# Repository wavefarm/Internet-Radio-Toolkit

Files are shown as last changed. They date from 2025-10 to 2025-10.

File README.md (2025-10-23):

Wave Farm's Transmission and Sound Art Toolkit

For organizations and Wave Farm Transmit Partners, the Transmission and Sound Art Toolkit is a self-contained kit that enables live audio streaming via WiFi using either the Toolkit’s built-in microphone or line-in audio. The Toolkit communicates with Wave Farm’s Icecast server to provide online audio streaming and automatically records and publishes audio archives. For artists, the Toolkit is an Arduino-based open source expandable platform for telematic performance and remote sonic and physical interaction.

This repo contains the hardware design files in EAGLE CAD format, manufacturing files, Arduino code and enclosure files in OpenSCAD and STL formats.

The project is based on the ESP32W-ROVER platform and the VLSI VS1063 IC.

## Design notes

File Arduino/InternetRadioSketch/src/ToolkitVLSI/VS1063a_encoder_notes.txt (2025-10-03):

Chapter 11.6 of the Data Sheet
------------------------------

Encoding Control Registers

SCI_MODE    bits 2,12,14 SM_RESET, SM_ENCODE, SM_LINE1
    Line 1 instead of mic is used if SM_LINE1 is set

SCI_AICTRL0 bits 15:0 Sample Rate 8000 - 48000 (read at encoding startup)

SCI_AICTRL1 bits 15:0 Gain 1024=1x 0=AGC
    gain is SCI_AICTRL1/1024

SCI_AICTRL2 Max autogain 1024=1x, 65535=64x

SCI_AICTRL3 15 codec mode (enable SDI data encoded to HDAT0 HDAT1)
            14 AEC enable (Acoustic Echo Cancellation)
            13 UART (8N1) TX enable (Send encoded data out the serial port)
                setup parametric_x.i.encoding for serial port params
            12 reserved, set to 0
            11 Pause enable
            10 No RIFF WAV header inserted (or expected)
            8:9 reserved set to 0
            7:4 encoding format 0 .. 6
                0=IMA ADPCM, 1=PCM, 5=Ogg, 6=MP3
            3 reserved set to 0
            2:0 ADC mode 0 .. 4
                0=joint stereo (common AGC), 1=dual stereo (separate AGC),
                2=left channel, 3=right channel, 4=mono mix

SCI_WRAMADDR bits 15:0 Quality/bit rate selection for Ogg and MP3
    Use 0xe080 for CBR 128kbps
            15:14 bitrate mode 0=quality mode, 1=VBR, 2=ABR, 3=CBR
            13:12 bit rate multiplier 0=10,1=100,2=1000,3=10000
            11 ogg specific
            10 mp3: 1=do not use bit-reservoir (bit reservoir is 1 frame back)
            9 set to 0
            8:0 bit rate base 0 to 511 (or quality 0 to 9 in quality mode)

IF you use VS1063a Patches:
    activate encoding mode by first setting the bit SM_ENCODE in SCI_MODE
    then write 0x50 to SCI_AIADDR

IF NOT using patches:
    set bits SM_RESET and SM_ENCODE in SCI_MODE

BEFORE ACTIVATING the encoder:
    the use MUST write values to SCI_AICTRL0, SCI_AICTRL3, and SC_WRAMADDR
    these values are only read at encoding startup
    SCI_AICTRL1 and SCI_AICTRL2 can be altered at anytime.

-----------------------------------------------------------------------------
11.6.2 THE ENCODING PROCEDURE

1. Load the patches package

2. Set
    SCI_CLOCKF to 4.5x (for all encoders except Ogg) 4.5x is default
    see 11.6.9,11.13

    SCI_AICTRL0 thru 3
    SCI_WRAMADDR

    Activate encoding for the patches or not

3. Recording
    read data through SCI_HDAT0/SCI_HDAT1
    see 11.6.3
    SCI_HDAT1 contains number of 2 byte words available (or 0 if none)
    SCI_HDAT0 contains big-endian 2 byte words of data, read until HDAT1 is 0

4 Finalizing
    set SM_CANCEL in SCI_MODE
    wait 100 ms
    read all remaining words from SCI_HDAT0/SCI_HDAT1
    wait 100ms
    soft reset

Example on Page 62 ****

    LoadUserCode(vs1063apatch);
    WriteVS10xxRegister(SCI_AICTRL0, 44100U);   // 44100Hz
    WriteVS10xxRegister(SCI_AICTRL1, 1024U);    // manual gain 1.0x
    WriteVS10xxRegister(SCI_AICTRL2, 4096U);    // AGC max gain 4.0x (not used)
    WriteVS10xxRegister(SCI_AICTRL3, 0x60);     // mp3, joint stereo

    WriteVS10xxRegister(SCI_WRAMADDR, 0xE080);  // 128kbps

    NOTE: we are loading WRAMADDR with a value but we are NOT doing subsequent
    WRAM access on this address value. The value is read at encoder startup,
    so no WRAM access occurs at all. Thus the value can be anything and it
    won't trash any WRAM data.

    uint16_t mode = ReadVS10xxRegister(SCI_MODE);
    mode = mode | SM_ENCODE | SM_LINE1;
    WriteVS10xxRegister(SCI_MODE, mode);
    WriteVS10xxRegister(SCI_AIADDR, 0x50);      // start recording

    Standard sample rates are: 32000, 44100, 48000

-----------------------------------------------------------------------------
Monitoring. SCI_VOL can be changed during encoding to change monitoring volume

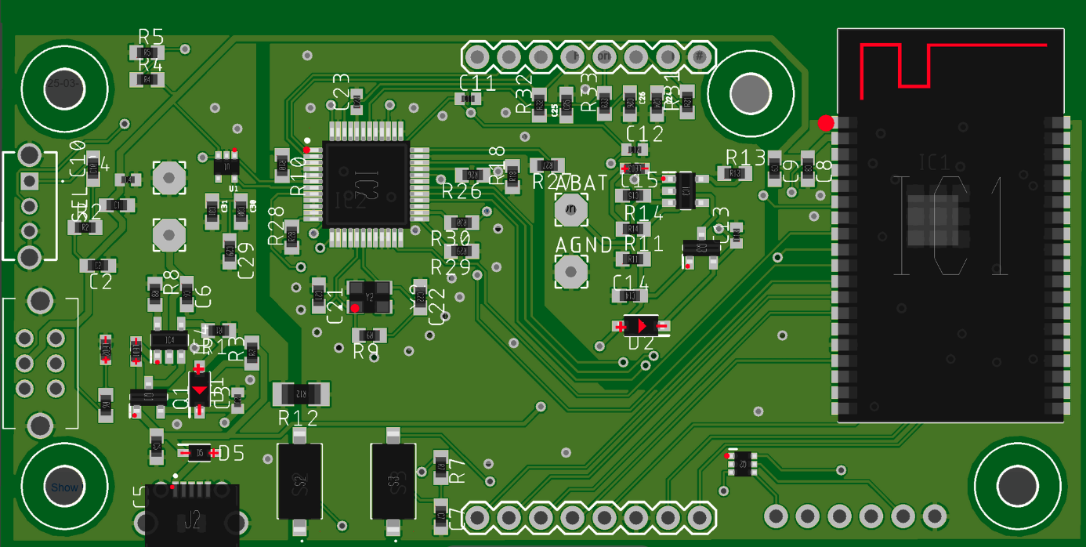
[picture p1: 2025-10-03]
Hardware/Gerbers/mainboard DFM.png

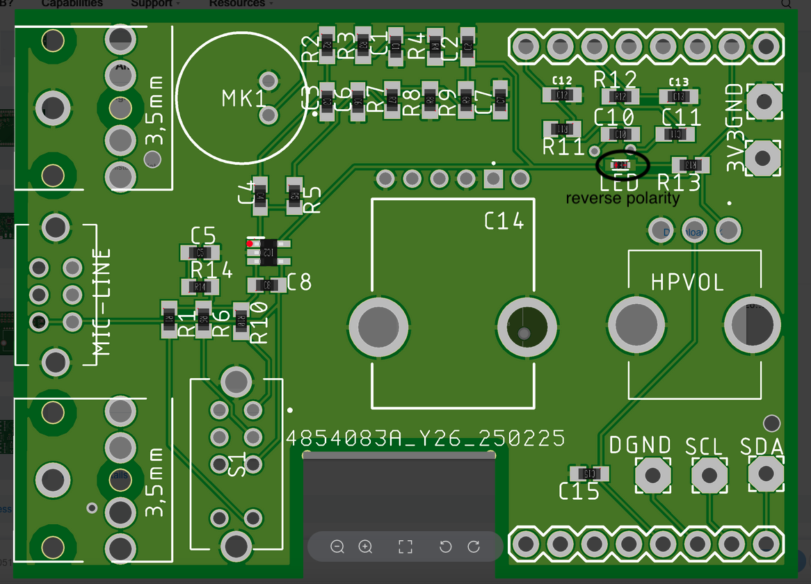
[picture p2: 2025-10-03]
Hardware/Gerbers/audioboard DFM.png

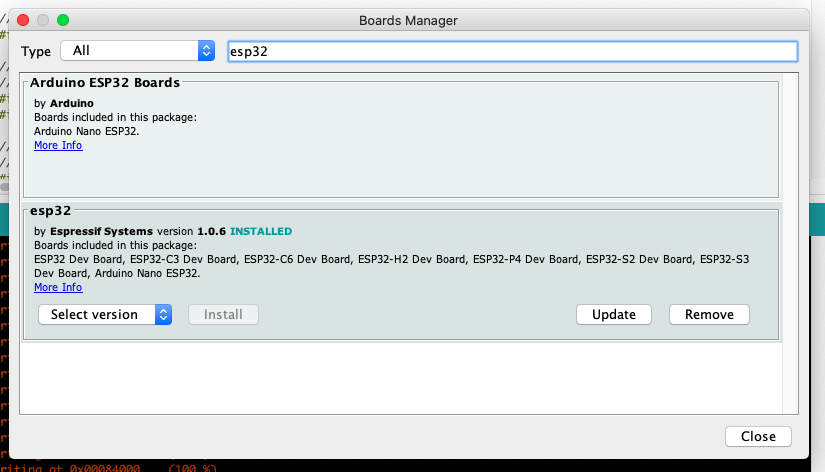
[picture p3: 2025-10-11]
Arduino/ide 1.8.19 settings/BoardManager_esp32_1.0.6.png

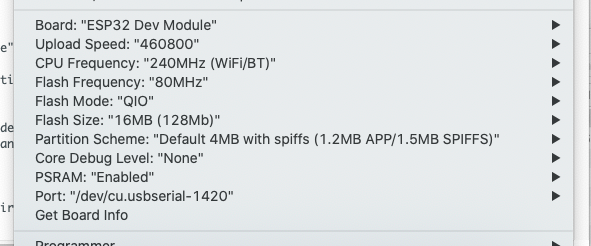
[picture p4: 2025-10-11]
Arduino/ide 1.8.19 settings/ToolMenu_BoardSettings.png

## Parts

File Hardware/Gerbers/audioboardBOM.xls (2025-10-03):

Comment | Designator | Footprint | JLCPCB Part #
10nF | C12,C13 | C0603 | C57112
R_18K_0603 | R5 | R0603 | C25810
R_15K_0603 | R7 | R0603 | C22809
C_47PF/50V_0603 | C3 | C0603 | C1671
LED | LED | SMARTLED-TTW | C273603
R_100R_0603 | R2 | R0603 | C22775
R_62K_0603 | R6 | R0603 | C23221
C_100NF/50V_0603 | C4 | C0603 | C14663
R_120K_0603 | R10 | R0603 | C25808
4K | R14 | R0603 | C2984443
C_100PF/50V_0603 | C8 | C0603 | C14858
MAX4466EXK+T | IC2 | SOT65P210X110-5N | C7456762
C_1UF/50V_0603 | C11,C10 | C0603 | C15849
C_2.2UF/16V_0603 | C6,C15 | C0603 | C23630
R_22K_0603 | R1 | R0603 | C31850
C_4.7UF/16V_0603 | C7 | C0603 | C19666
R_1K_0603 | R4 | R0603 | C21190
R_100K_0603 | R9,R8 | R0603 | C25803
R_470R_0603 | R12,R11 | R0603 | C23179
C_10UF/10V_0603 | C2,C1,C5 | C0603 | C19702
R_2.2K_0603 | R13,R3 | R0603 | C4190

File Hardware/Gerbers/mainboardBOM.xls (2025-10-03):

Comment | Designator | Footprint | JLCPCB Part #
R_0R_1206 | R12 | R1206 | C17888
10nF | C25,C24 | 0603-CAP | C57112
47nF | C26 | 0603-CAP | C1622
BAT760-7 | D5 | SOD2513X120N | C124187
MICROXNJ | J2 | MICROXNJ | C404969
VS1063A-L | IC2 | QFP50P900X900X160-48N | C486306
SXT32422AA48 | Y2 | SXT32422AA48 | C2901653
100nF | C31,C10,C7,C2,C30,C9 | C0603 | C14663
20 | R32,R31 | R0603 | C22950
Charge | LED2,LED1,LED3 | CHIP-LED0603 | C2286
10uF | C15,C14,C8,C29,C1,C6,C5 | C0603 | C19702
2k | R13,R14,R6,R3,R8 | R0603 | C22975
CJ2301_S1 | Q1,Q3 | SOT95P240X115-3N | C8547
UMH3NTN | Q2 | UMH3NTN | C123008
1uF | C23,C4,C12,C13,C11,C3 | C0402 | C52923
10 | R33 | R0603 | C22859
B5819W | D2,D1 | SOD3716X125N | C393519
TP4054-42-SOT25-R | IC3,IC4 | SOT95P280X100-5N | C32574
1.8V | U1 | SC70 | C266774
1M | R9 | R0603 | C22935
TS-1101-C-W | S2,S3 | TS1101CW | C318938
10k | R2,R7 | R0603 | C25804
100k | R4,R18,R27,R29,R30,R11,R1,R10,R28,R5,R26 | R0603 | C25803
22pF | C21,C22 | C0603 | C1634
ESP32-WROVER-E | IC1 | ESP32WROVERE | C529589

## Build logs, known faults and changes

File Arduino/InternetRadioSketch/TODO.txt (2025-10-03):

------------------------------------------------------------------------------
(1)
Add Kiosk mode

(a) kiosk_mode = 0 | 1 .. set via the hardware switch
if the hardware switch is ON (1) and there is a 'kiosk.html' file,
then serve kiosk.html .. otherwise operate with the normal
index.html file. The kiosk will stream whichever listen/transmit
stream is running through the system.

(b) if the transmit icy url == "" then we don't connect to an icy server
but we still stream through mp3 to the wifi server

(c) when the wifi server starts up it notes the startup ..
    _server_start_time = millis();
    _server_two_minute_timeout = false;
    _server_use_kiosk_page = false;

(d) when wifi server runs ..
    if (!_server_two_minute_timeout) {
        now = millis();
        if ((now - _server_start_time) > (120*1000)) {
            _server_two_minute_timeout = true;
            if (SettingItem::findUInt("kiosk_mode_is_on", 0)) {
                _server_use_kiosk_page = true;
            }
        }
    }

(e) kiosk.html
Use the play button + audio tag like in the config page, but make the
audio tag become visible only after the play button has been pressed.

------------------------------------------------------------------------------
(DONE)
Physical controls:
Peter your "listening mode selection" switch aka browser or icecast will be
coming in hot on pin 15 and the volume control pot will be on pin 35

------------------------------------------------------------------------------
(DONE)
Newer way to do load-on-play with the audio element

<audio controls="controls" preload="none">
</audio>

------------------------------------------------------------------------------
(DONE)
JS stuff for handling mobile

document.addEventListener("visibilitychange", () => {
  if (document.visibilityState === "hidden") {
    // We are now in the background
    // close the WS connection
  } else {
    // We have just come into the foreground
    // reconnect to the WS
  }
});

CHANGE the focus handler so that it checks for a connection and only
reconnects if we are disconnected.

------------------------------------------------------------------------------
(DONE)
Make the post file code compatible with binary uploads
i.e. we can't use the \0 terminator as a way to find the end
of the input buffer.

------------------------------------------------------------------------------
(DONE)
Change large static http buffer to a inbetween stream buffer

-> we want to use a short static buffer for GET requests and WS messages
-> BUT we need to be able to stream in POST requests
 The POST requests will have to block the server thread until the POST
 is finished.

------------------------------------------------------------------------------
(DONE)
UPLOAD page works.
We also need to support changing the Router SSID and Password via the default
page.
And the page should also post the local IP4 address if it knows it.
And also the AP IP4 address so you can use it on your phone

------------------------------------------------------------------------------
(DONE) .. maybe we can fix the bug when reconnecting to the AP on a phone

If the AP login page is still sitting in the browser then it assumes
that everything is already loaded and doesn't do a new load event.

window.addEventListener("focus", function(event)
{
    // check to make sure the WS is running and has updated settings
}, false);

We could add this into the static initializer of the toolkitSocket class.
It should look like this ..

    window.addEventListener("focus", function(event)
    {
        if (toolkitSocket.isConnected()) {
            toolkitSocket.close();
        }
        setTimeout(function() {
            toolkitSocket.open();
        }, 500);
    }, false);

    try this and see if it works .. so that we refresh the settings
    whenever we regain focus.

------------------------------------------------------------------------------
(DONE)
Some of the captive portal page commands need to be "live"

- listening volume .. can be changed in realtime

- can the agc/manual volume be changed during a recording?
SCI_AICTRL1 - 16 bits encoder gain 1024 = 1.0 or 0 for AGC
SCI_AICTRL2 - 16 bits max AGC 1024 = 1.0, 64x-1 is the maximum

- changing between Transmitter and Kiosk mode could be done in realtime
  (see below)

------------------------------------------------------------------------------
(DONE)

Echo WS settings messages to all WS connections to keep all clients in sync

THIS means redoing a bunch of code, since some of it is static and some
is part of the non-static buy single ToolkitWiFi code

boolean websocket_handleIncoming(const char *buffer, size_t size)
    // then we an also handle the messages that cause "live" updates
    // volume, ..

needs to become part of ToolkitWiFi .. then we can add
a send to other WS connections function (name, value)
using websocket_sendString(twfc, const char *)

------------------------------------------------------------------------------
(DONE)

Do we miss server requests because the packets are either split or merged?
This might be why the captive portal breaks once in a while.

ALSO we close the http socket right away and don't allow the browser to
reuse it .. might make sense to have a timeout for that so that the
socket stays open unless it hasn't been used for a few milliseconds.

(a) update the http request receiver code to check for multiple requests

(b) keep the connection open for 1 second beyond the last request.
It should probably be set back to type UNKNOWN once a request has been
handled.

------------------------------------------------------------------------------
(MAYBE NOT NEEDED) now that the streaming code is fixed
sometimes it is better to let the driver do what it likes to do.

client.setNoDelay(true);  // set this on the icy and mp3 clients

------------------------------------------------------------------------------
(DONE)

set encoder and listener task priorities to 2
(so that they don't get stalled by the WiFi streaming)

move WiFi server task and icecast reconnect tasks to CPU 0

increase WiFi server head size .. seems to clear up the stalling on
the WiFi writes .. maybe there is some weird swap stuff going on with
the big buffers once they have been passed to the esp32 WiFi code.

------------------------------------------------------------------------------
(DONE) .. prints out an error message if we timeout

size_t client.write(data, size) // check the actual bytes sent

------------------------------------------------------------------------------
(DONE)

Changed buffer stream to hold 3 seconds at 128kbps.

It is a rotating buffer that will write over itself if the outgoing
stream doesn't run fast enough.

Outgoing stream runs 2 or more buffers behind the incoming stream.

------------------------------------------------------------------------------

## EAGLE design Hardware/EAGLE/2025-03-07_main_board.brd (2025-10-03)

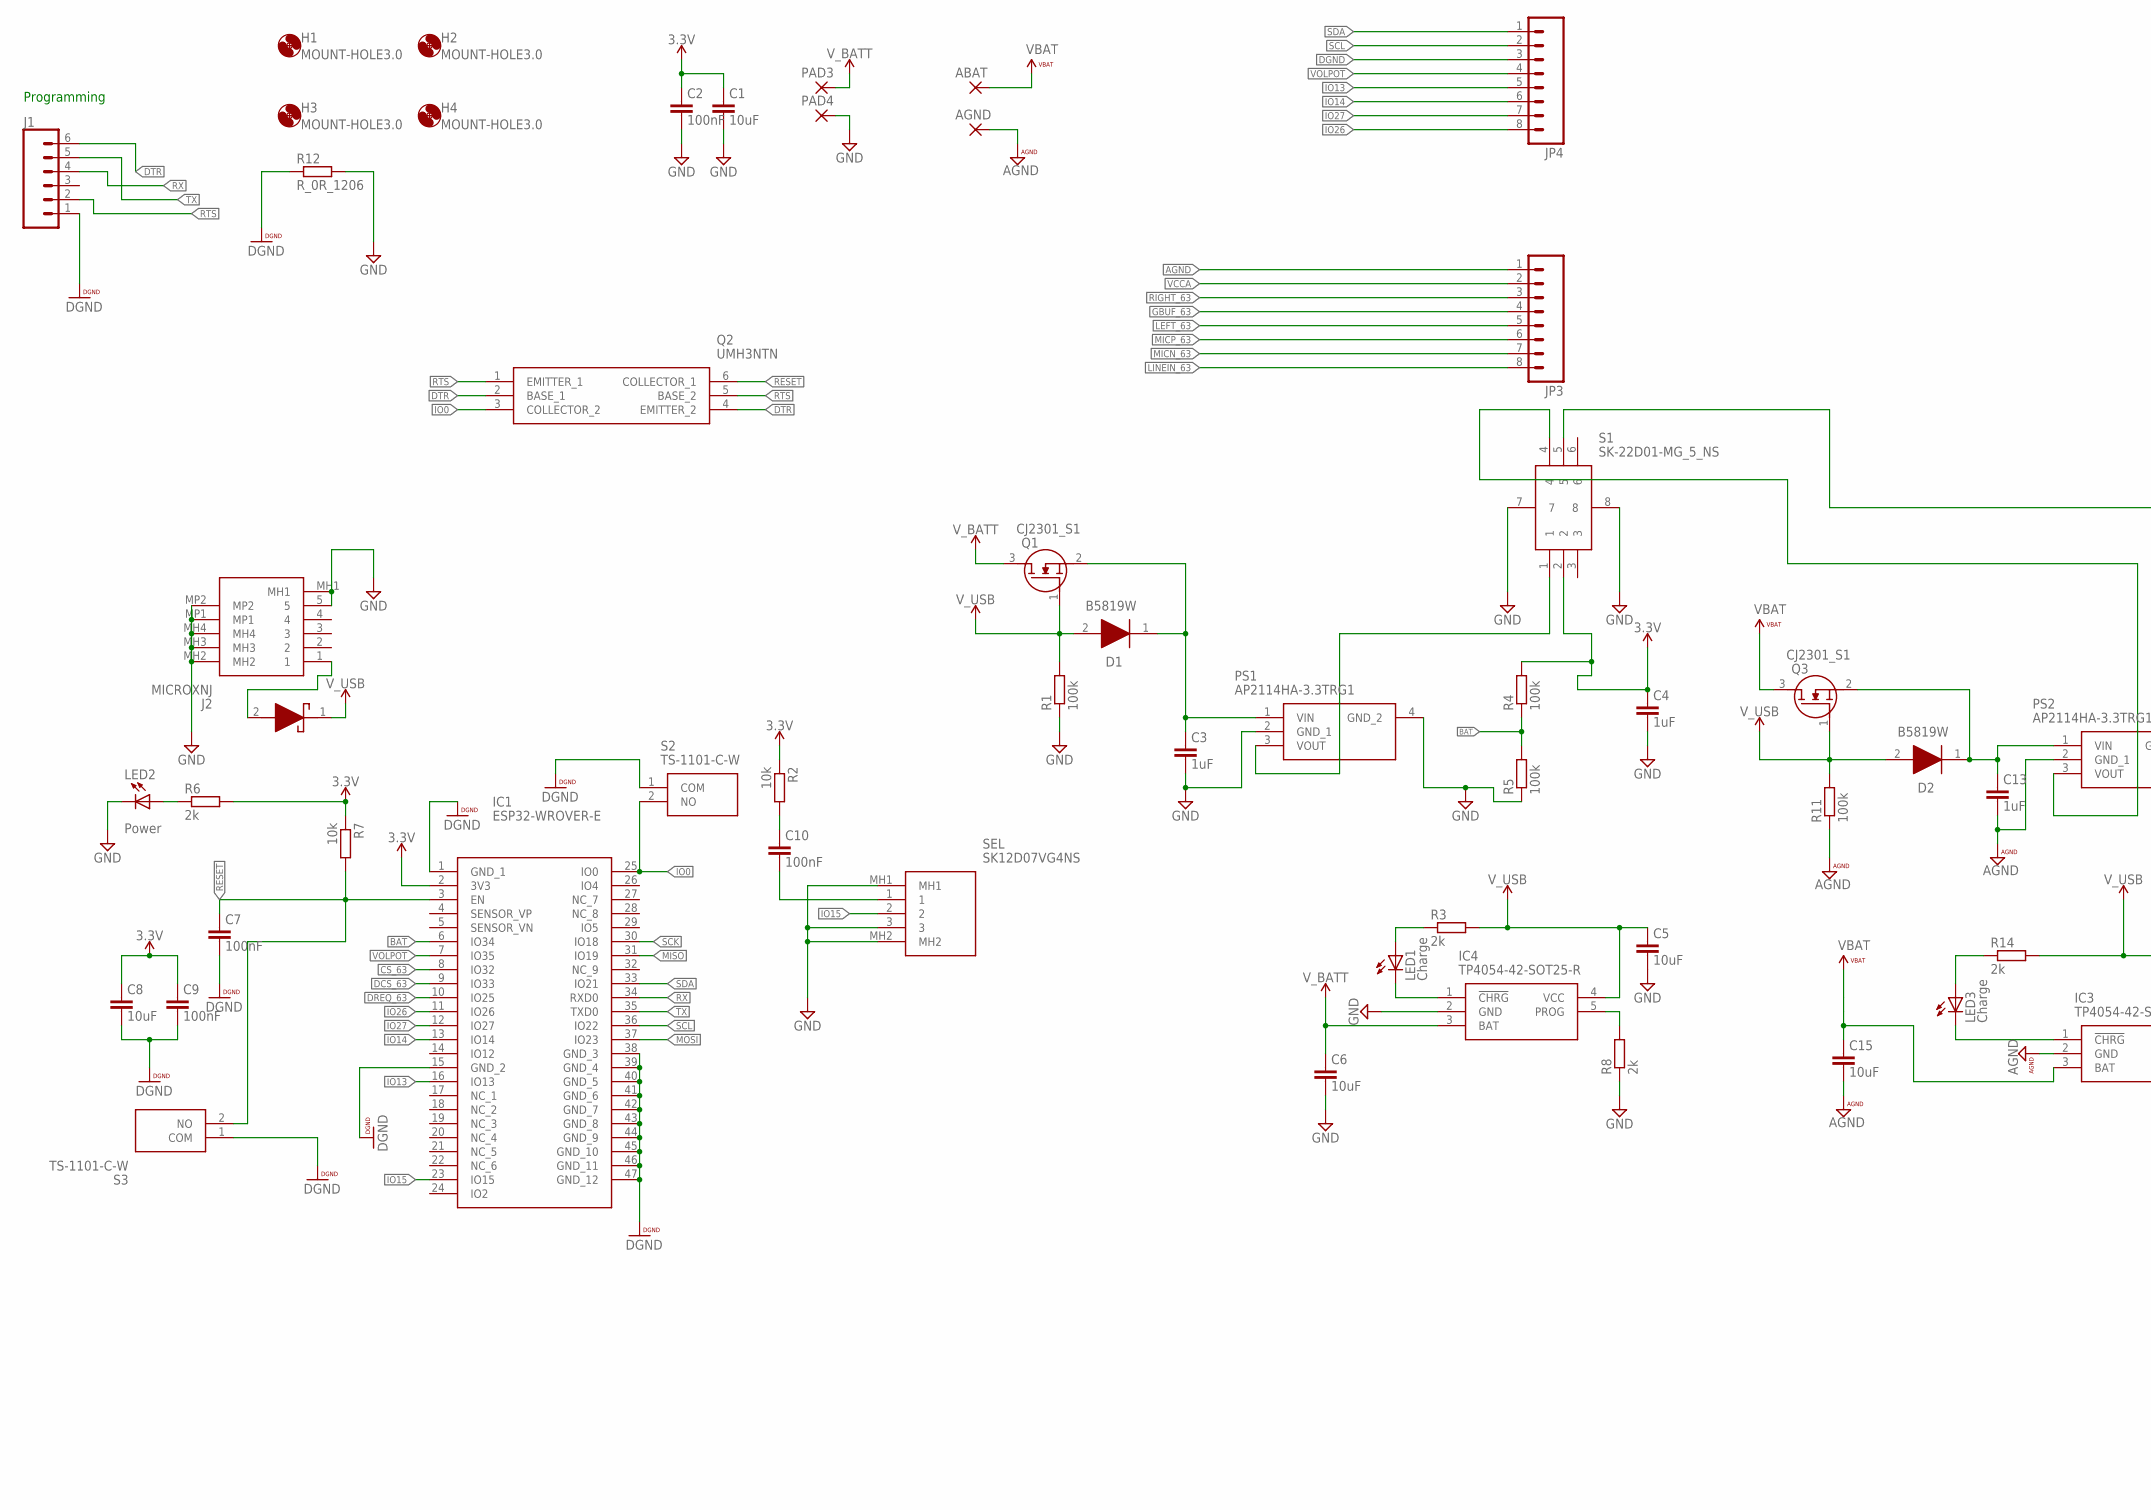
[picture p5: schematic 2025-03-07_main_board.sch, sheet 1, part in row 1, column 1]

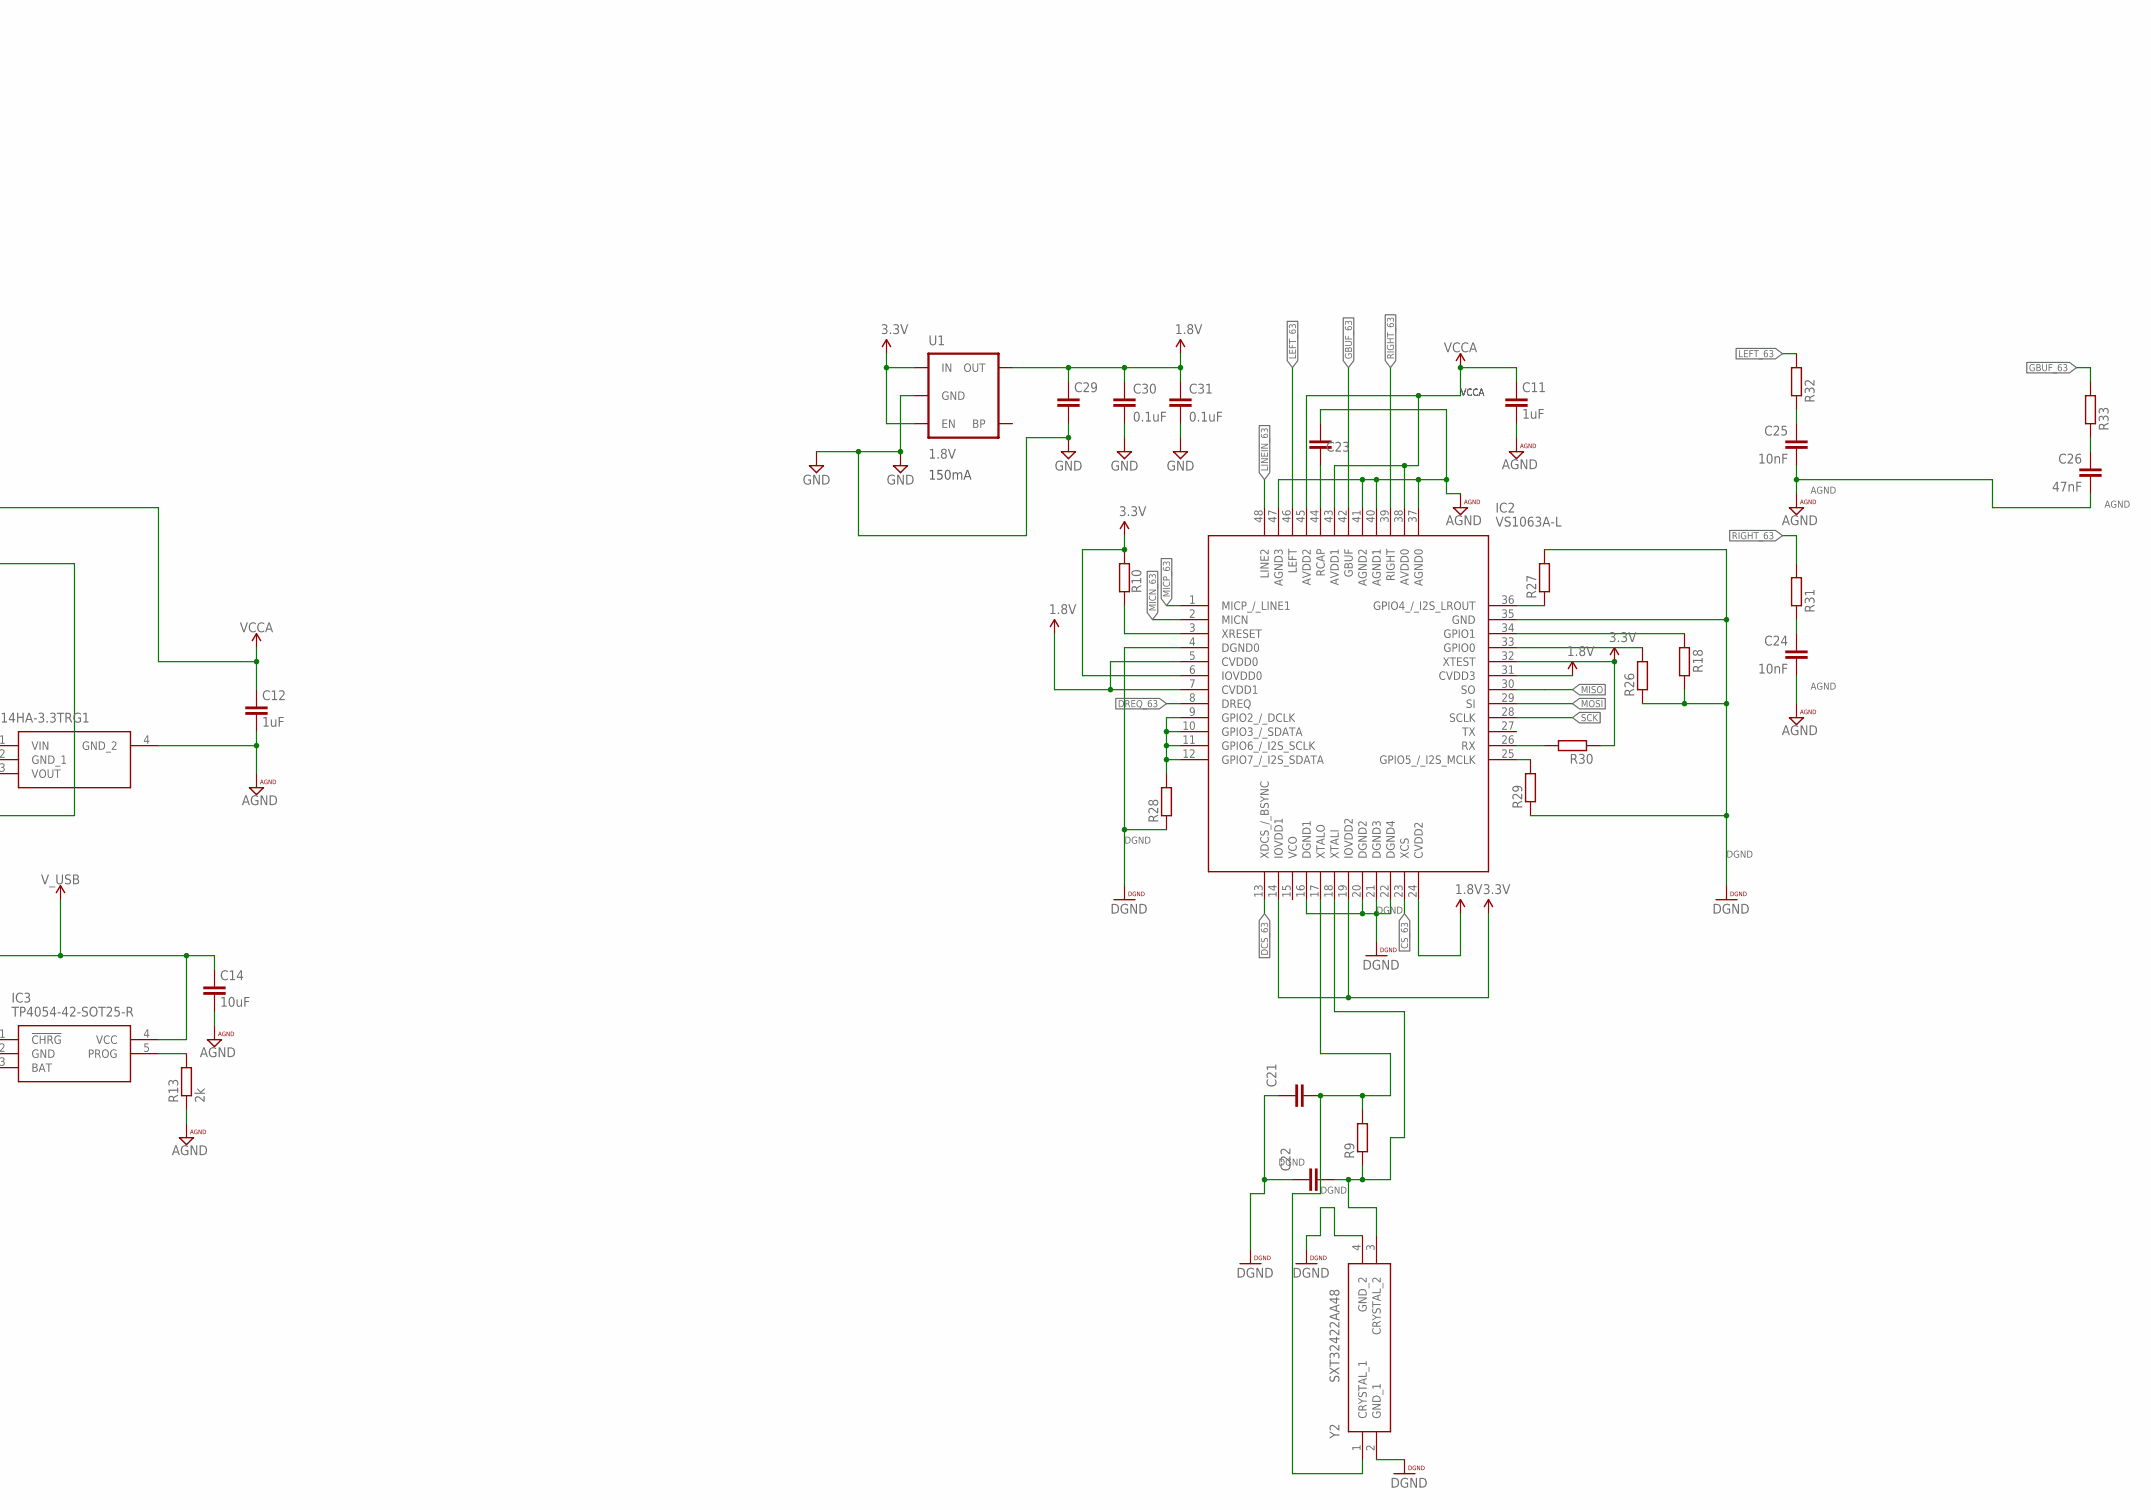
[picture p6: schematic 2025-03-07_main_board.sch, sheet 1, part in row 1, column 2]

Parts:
ABAT: 2,54/0,8
AGND: 2,54/0,8
C1, C5, C6, C8, C14, C15, C29: 10uF; C0603
C2, C7, C9, C10: 100nF; C0603
C3, C4, C11, C12, C13: 1uF; C0402
C21, C22: 22pF; C0603
C23: 1.0uF; C0402
C24, C25: 10nF; 0603-CAP
C26: 47nF; 0603-CAP
C30, C31: 0.1uF; 0603-CAP
D1, D2: B5819W; SOD3716X125N
D5: BAT760-7; SOD2513X120N
H1, H2, H3, H4: MOUNT-HOLE3.0; 3,0
IC1: ESP32-WROVER-E; ESP32WROVERE
IC2: VS1063A-L; QFP50P900X900X160-48N
IC3, IC4: TP4054-42-SOT25-R; SOT95P280X100-5N
J1: CONN_06NO_SILK_FEMALE_PTH; 1X06_NO_SILK
J2: MICROXNJ
JP3, JP4: M08; 1X08_ROUND
LED1, LED3: Charge; CHIP-LED0603
LED2: Power; CHIP-LED0603
PAD3, PAD4: 2,54/0,8
PS1, PS2: AP2114HA-3.3TRG1; SOT230P700X180-4N
Q1, Q3: CJ2301_S1; SOT95P240X115-3N
Q2: UMH3NTN
R1, R4, R5, R10, R11, R18, R26, R27, R28, R29, R30: 100k; R0603
R2, R7: 10k; R0603
R3, R6, R8, R13, R14: 2k; R0603
R9: 1M; R0603
R12: R_0R_1206; R1206
R31, R32: 20; R0603
R33: 10; R0603
S1: SK-22D01-MG_5_NS; SK22D01MG5NS
S2, S3: TS-1101-C-W; TS1101CW
SEL: SK12D07VG4NS
U1: 1.8V; SC70
Y2: SXT32422AA48

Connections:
1.8V: C29.1, C30.1, C31.1, IC2.5 (CVDD0), IC2.7 (CVDD1), IC2.24 (CVDD2), IC2.31 (CVDD3), U1.5 (OUT)
3.3V: C1.1, C2.1, C4.1, C8.1, C9.1, IC1.2 (3V3), IC2.6 (IOVDD0), IC2.14 (IOVDD1), IC2.19 (IOVDD2), IC2.32 (XTEST), R2.1, R4.2, R6.2, R7.1, R10.2, R30.1, S1.2, U1.1 (IN), U1.3 (EN)
AGND: AGND.1, C11.2, C12.2, C13.2, C14.2, C15.2, C23.2, C24.2, C25.2, C26.2, IC2.37 (AGND0), IC2.40 (AGND1), IC2.41 (AGND2), IC2.47 (AGND3), IC3.2 (GND), JP3.1, PS2.2 (GND_1), PS2.4 (GND_2), R11.1, R13.1
BAT: IC1.6 (IO34), R4.1, R5.2
CS_63: IC1.8 (IO32), IC2.23 (XCS)
DCS_63: IC1.9 (IO33), IC2.13 (XDCS_/_BSYNC)
DGND: C7.2, C8.2, C9.2, C21.1, C22.1, IC1.1 (GND_1), IC1.15 (GND_2), IC1.38 (GND_3), IC1.39 (GND_4), IC1.40 (GND_5), IC1.41 (GND_6), IC1.42 (GND_7), IC1.43 (GND_8), IC1.44 (GND_9), IC1.45 (GND_10), IC1.46 (GND_11), IC1.47 (GND_12), IC2.4 (DGND0), IC2.16 (DGND1), IC2.20 (DGND2), IC2.21 (DGND3), IC2.22 (DGND4), IC2.35 (GND), J1.1, JP4.3, R12.1, R18.1, R26.1, R27.2, R28.1, R29.1, S2.1 (COM), S3.1 (COM), Y2.2 (GND_1), Y2.4 (GND_2)
DREQ_63: IC1.10 (IO25), IC2.8 (DREQ)
DTR: J1.6, Q2.2 (BASE_1), Q2.4 (EMITTER_2)
GBUF_63: IC2.42 (GBUF), JP3.4, R33.2
GND: C1.2, C2.2, C3.2, C4.2, C5.2, C6.2, C29.2, C30.2, C31.2, IC4.2 (GND), J2.5, J2.MH1, J2.MH2, J2.MH3, J2.MH4, J2.MP1, J2.MP2, LED2.C, PAD4.1, PS1.2 (GND_1), PS1.4 (GND_2), R1.1, R5.1, R8.1, R12.2, S1.7, S1.8, SEL.3, SEL.MH1, SEL.MH2, U1.2 (GND)
IO0: IC1.25 (IO0), Q2.3 (COLLECTOR_2), S2.2 (NO)
IO13: IC1.16 (IO13), JP4.5
IO14: IC1.13 (IO14), JP4.6
IO15: IC1.23 (IO15), SEL.2
IO26: IC1.11 (IO26), JP4.8
IO27: IC1.12 (IO27), JP4.7
LEFT_63: IC2.46 (LEFT), JP3.5, R32.2
LINEIN_63: IC2.48 (LINE2), JP3.8
MICN_63: IC2.2 (MICN), JP3.7
MICP_63: IC2.1 (MICP_/_LINE1), JP3.6
MISO: IC1.31 (IO19), IC2.30 (SO)
MOSI: IC1.37 (IO23), IC2.29 (SI)
unnamed: PS1.3 (VOUT), S1.1
unnamed: C3.1, D1.1 (K), PS1.1 (VIN), Q1.2 (S)
unnamed: LED2.A, R6.1
unnamed: IC4.1 (!CHRG), LED1.C
unnamed: LED1.A, R3.1
unnamed: D5.2 (A), J2.1
unnamed: IC4.5 (PROG), R8.2
unnamed: C13.1, D2.1 (K), PS2.1 (VIN), Q3.2 (S)
unnamed: C10.1, R2.2
unnamed: C10.2, SEL.1
unnamed: IC2.3 (XRESET), R10.1
unnamed: IC2.34 (GPIO1), R18.2
unnamed: IC3.1 (!CHRG), LED3.C
unnamed: LED3.A, R14.1
unnamed: PS2.3 (VOUT), S1.4
unnamed: C21.2, IC2.17 (XTALO), R9.2, Y2.1 (CRYSTAL_1)
unnamed: IC2.36 (GPIO4_/_I2S_LROUT), R27.1
unnamed: IC2.33 (GPIO0), R26.2
unnamed: C22.2, IC2.18 (XTALI), R9.1, Y2.3 (CRYSTAL_2)
unnamed: C23.1, IC2.44 (RCAP)
unnamed: IC2.25 (GPIO5_/_I2S_MCLK), R29.2
unnamed: IC3.5 (PROG), R13.2
unnamed: IC2.9 (GPIO2_/_DCLK), IC2.10 (GPIO3_/_SDATA), IC2.11 (GPIO6_/_I2S_SCLK), IC2.12 (GPIO7_/_I2S_SDATA), R28.2
unnamed: IC2.26 (RX), R30.2
unnamed: C26.1, R33.1
unnamed: C25.1, R32.1
unnamed: C24.1, R31.1
RESET: C7.1, IC1.3 (EN), Q2.6 (COLLECTOR_1), R7.2, S3.2 (NO)
RIGHT_63: IC2.39 (RIGHT), JP3.3, R31.2
RTS: J1.2, Q2.1 (EMITTER_1), Q2.5 (BASE_2)
RX: IC1.34 (RXD0), J1.4
SCK: IC1.30 (IO18), IC2.28 (SCLK)
SCL: IC1.36 (IO22), JP4.2
SDA: IC1.33 (IO21), JP4.1
TX: IC1.35 (TXD0), J1.5
VBAT: ABAT.1, C15.1, IC3.3 (BAT), Q3.3 (D)
VCCA: C11.1, C12.1, IC2.38 (AVDD0), IC2.43 (AVDD1), IC2.45 (AVDD2), JP3.2, S1.5
VOLPOT: IC1.7 (IO35), JP4.4
V_BATT: C6.1, IC4.3 (BAT), PAD3.1, Q1.3 (D)
V_USB: C5.1, C14.1, D1.2 (A), D2.2 (A), D5.1 (K), IC3.4 (VCC), IC4.4 (VCC), Q1.1 (G), Q3.1 (G), R1.2, R3.2, R11.2, R14.2

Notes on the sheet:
Programming
150mA

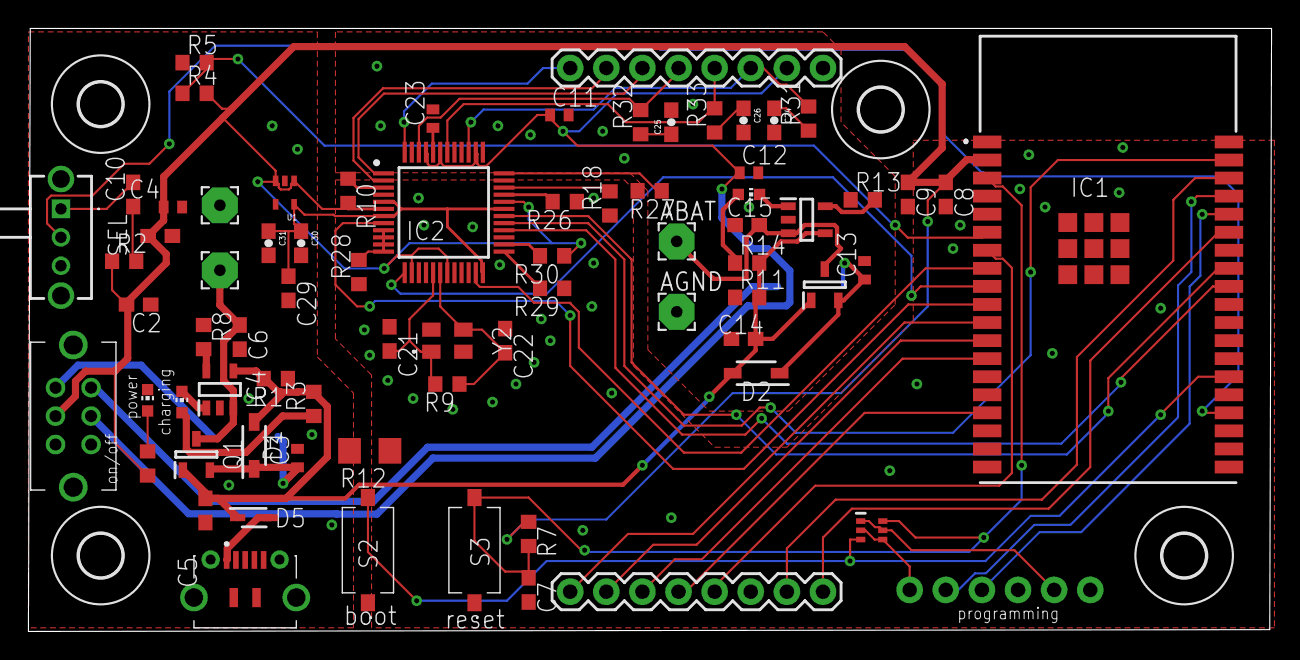
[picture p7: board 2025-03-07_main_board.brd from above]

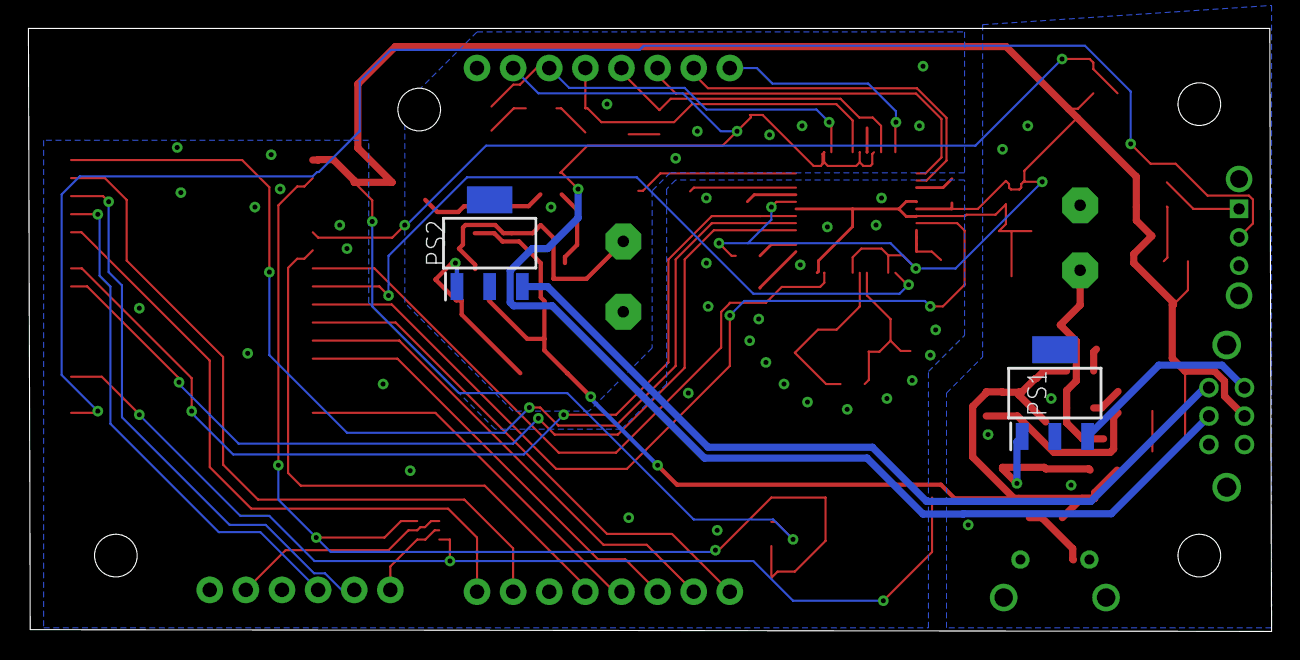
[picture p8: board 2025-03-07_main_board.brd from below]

Board: 2 copper layers, 87.4 x 42.4 mm, 80 parts (2 on the bottom side), 63 nets.

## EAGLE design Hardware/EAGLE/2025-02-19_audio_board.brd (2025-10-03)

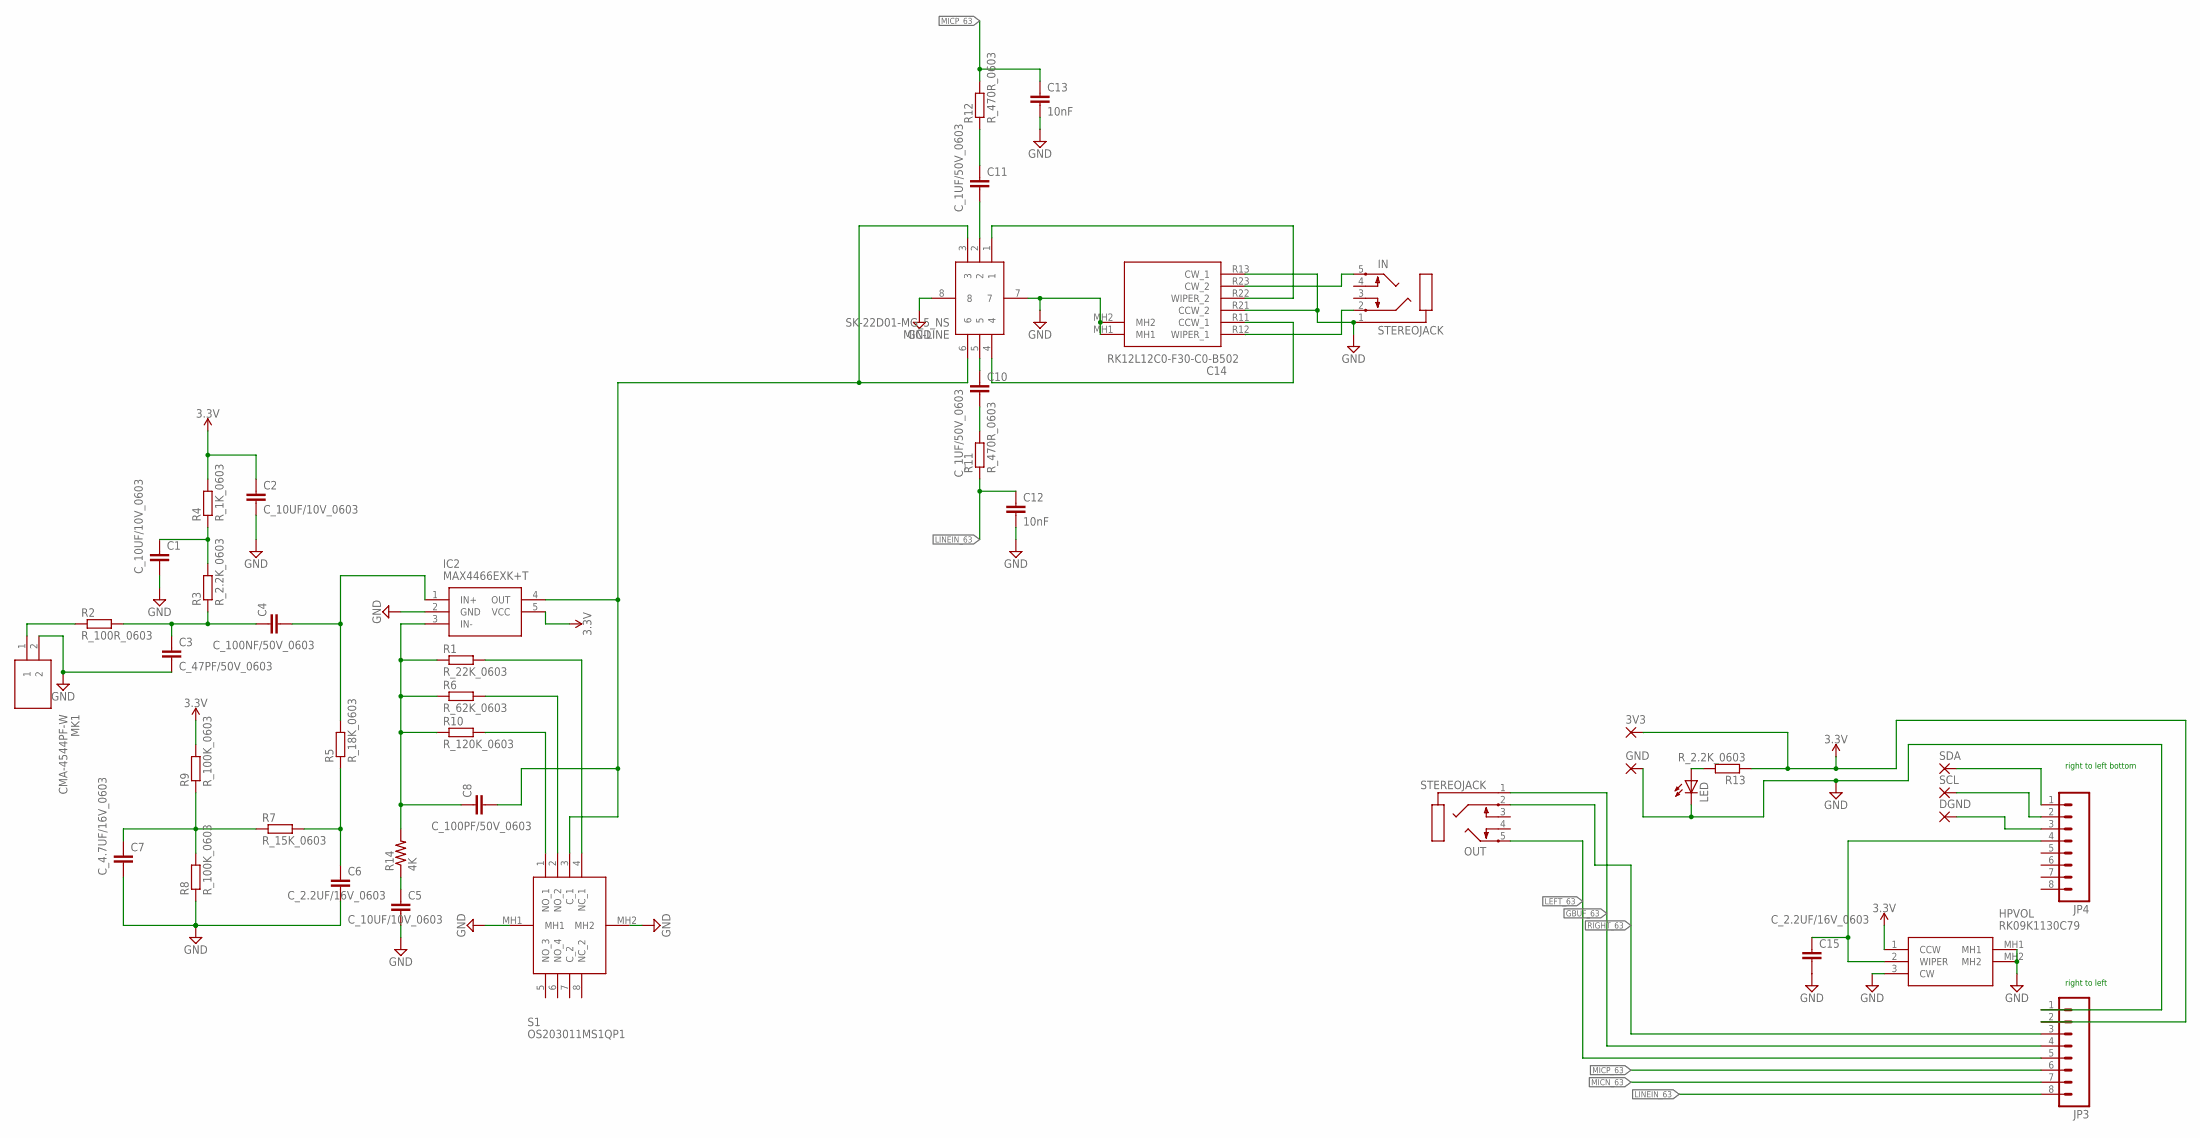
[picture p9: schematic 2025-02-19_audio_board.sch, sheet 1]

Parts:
3V3: 2,54/1,0
C1, C2, C5: C_10UF/10V_0603; C0603
C3: C_47PF/50V_0603; C0603
C4: C_100NF/50V_0603; C0603
C6, C15: C_2.2UF/16V_0603; C0603
C7: C_4.7UF/16V_0603; C0603
C8: C_100PF/50V_0603; C0603
C10, C11: C_1UF/50V_0603; C0603
C12, C13: 10nF; 0603
C14: RK12L12C0-F30-C0-B502; RK12L12C0F30C0B502
DGND: 2,54/1,0
GND: 2,54/1,0
HPVOL: RK09K1130C79
IC2: MAX4466EXK+T; SOT65P210X110-5N
IN: STEREOJACK; STX3100
JP3, JP4: M08; 1X08_ROUND
LED: LED; SMARTLED-TTW
MIC-LINE: SK-22D01-MG_5_NS; SK22D01MG5NS
MK1: CMA-4544PF-W; CMA4544PFW
OUT: STEREOJACK; STX3100
R1: R_22K_0603; R0603
R2: R_100R_0603; R0603
R3, R13: R_2.2K_0603; R0603
R4: R_1K_0603; R0603
R5: R_18K_0603; R0603
R6: R_62K_0603; R0603
R7: R_15K_0603; R0603
R8, R9: R_100K_0603; R0603
R10: R_120K_0603; R0603
R11, R12: R_470R_0603; R0603
R14: 4K; R0603
S1: OS203011MS1QP1
SCL: 2,54/1,0
SDA: 2,54/1,0

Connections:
3.3V: 3V3.1, C2.1, HPVOL.1 (CCW), IC2.5 (VCC), JP3.2, R4.2, R9.2, R13.1
GBUF_63: JP3.4, OUT.1
GND: C1.2, C2.2, C3.2, C5.2, C6.2, C7.2, C12.2, C13.2, C14.MH1, C14.MH2, C14.R13 (CW_1), C14.R21 (CCW_2), C15.2, GND.1, HPVOL.3 (CW), HPVOL.MH1, HPVOL.MH2, IC2.2 (GND), IN.1, JP3.1, LED.C@1 (C), MIC-LINE.7, MIC-LINE.8, MK1.2, R8.1, S1.MH1, S1.MH2
LEFT_63: JP3.5, OUT.5
LINEIN_63: C12.1, JP3.8, R11.1
MICN_63: JP3.7
MICP_63: C13.1, JP3.6, R12.2
unnamed: MK1.1, R2.1
unnamed: C3.1, C4.1, R2.2, R3.1
unnamed: LED.A@1 (A), R13.2
unnamed: C5.1, R14.1
unnamed: C6.1, R5.1, R7.2
unnamed: C1.1, R3.2, R4.1
unnamed: C8.1, IC2.3 (IN-), R1.1, R6.1, R10.1, R14.2
unnamed: JP4.1, SDA.1
unnamed: JP4.2, SCL.1
unnamed: R1.2, S1.4 (NC_1)
unnamed: R6.2, S1.2 (NO_2)
unnamed: C11.2, MIC-LINE.2
unnamed: R10.2, S1.1 (NO_1)
unnamed: C10.2, R11.2
unnamed: C10.1, MIC-LINE.5
unnamed: C14.R22 (WIPER_2), MIC-LINE.1
unnamed: C11.1, R12.1
unnamed: C14.R23 (CW_2), IN.5
unnamed: DGND.1, JP4.3
unnamed: C14.R12 (WIPER_1), IN.2
unnamed: C14.R11 (CCW_1), MIC-LINE.4
unnamed: C15.1, HPVOL.2 (WIPER), JP4.4
OAIN: C4.2, IC2.1 (IN+), R5.2
OAOUT: C8.2, IC2.4 (OUT), MIC-LINE.3, MIC-LINE.6, S1.3 (C_1)
RIGHT_63: JP3.3, OUT.2
VHALF: C7.1, R7.1, R8.2, R9.1

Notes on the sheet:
right to left bottom
right to left

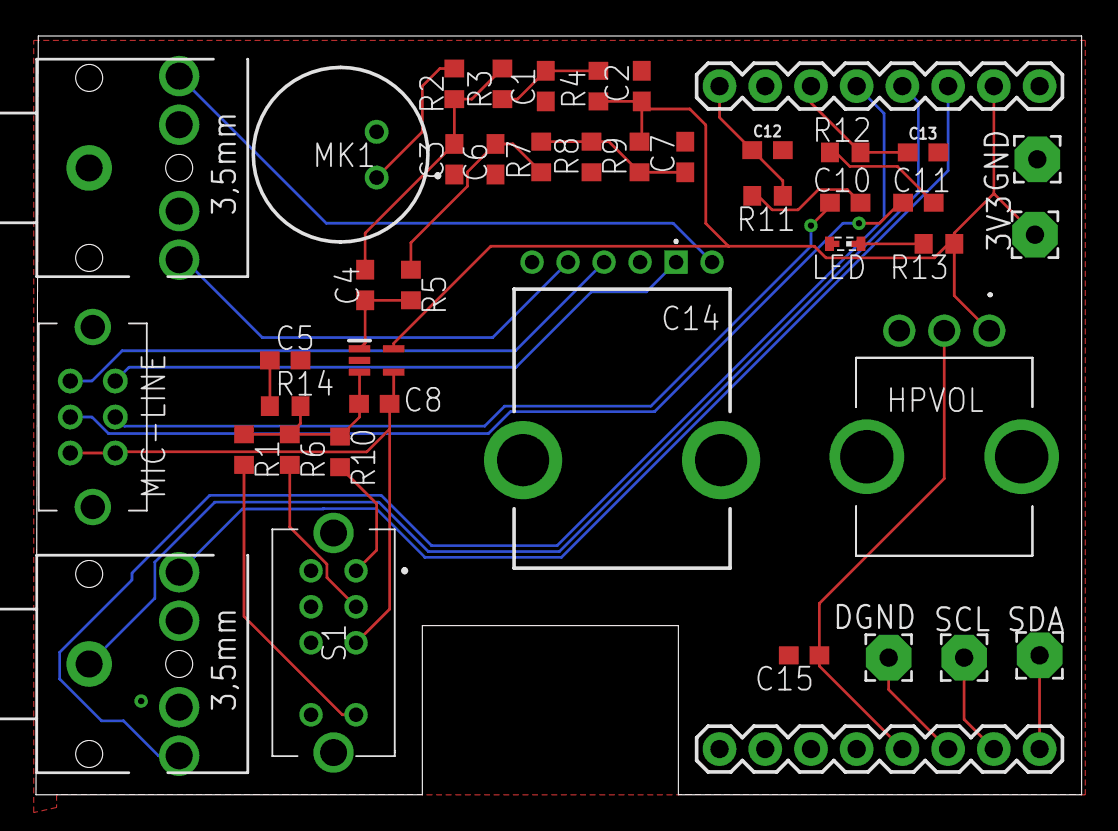
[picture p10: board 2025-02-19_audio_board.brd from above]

Board: 2 copper layers, 58.1 x 42.2 mm, 43 parts (0 on the bottom side), 32 nets.

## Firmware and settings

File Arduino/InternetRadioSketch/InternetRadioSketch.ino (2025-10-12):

//
// Wave Farm Toolkit for audio streaming
// October/November 2024
//

// Tested with Arduino 1.8.19 and 2.3.6
// Esp32 v 1.0.6 ("ESP32 Dev Module")

// config contains compile time options for RTOS
#include "config.h"

// default settings and default index page are used if the SPIFFS
// is not setup with settings.txt and index.html
#include "DefaultSettings.h"
#include "DefaultIndexPage.h"

// Include for local/project libraires
// VLSI VS10xx
#include "Streamer.h"
#include "src/ToolkitFiles/ToolkitFiles.h"
#include "src/ToolkitWiFi/ToolkitWiFi_Server.h"

// Include hardware controls (volume knob and mode switch)
#if USE_PIN_CONTROLS
#include "PinControls.h"
PinControls pins_thing;
#endif

// These objects connect us with the Toolkit VLSI and WiFi Server
Streamer stream_thing;
ToolkitWiFi_Server wifi_thing;

//------------------------------------------------------------------------------------
//
// There are four main tasks that we need to run in the loop()
//

void server_task(void *params)
{
  const int delay_in_ms = RTOS_DELAY_SERVER_TASK;
  while (true) {
    wifi_thing.run();
    vTaskDelay(portTICK_PERIOD_MS * delay_in_ms);
  }
}

void listen()
{
  while (stream_thing.readyForData()) { // wait till mp3 wants more data
    //wants more data! check we have something available from the stream
    if (stream_thing.reconnect_listener_if_needed()) {
      if (stream_thing.listener.available() > 0) {
      
        size_t remaining = 0;
        uint8_t *buffer = stream_thing.getNextInBuffer(&remaining);
        if (remaining > 32) {
          remaining = 32;
        }
      
        uint8_t bytesused = stream_thing.listener.read(buffer, remaining);
        stream_thing.playData(buffer, bytesused); // send to the VS1063a audio output
        stream_thing.advanceInBuffer(bytesused);
  
      } // end of listener.available()
    } else { // end of reconnect_listener_if_needed()
      Serial.println("Listener has disconnected .. will try to reconnect in 10 seconds.");
      vTaskDelay(portTICK_PERIOD_MS * 10000);
    }
  } // end of while readyForData()  
}

void listener_task(void *params)
{
  const int delay_in_ms = RTOS_DELAY_LISTENER_TASK;  // 250ms per 128kbps buffer
  while (true) {
    listen();
    vTaskDelay(portTICK_PERIOD_MS * delay_in_ms);
  } // end of while (true)
}

void encode()
{
  if (stream_thing.readyForData()) {
    size_t remaining = 0;
    uint8_t *buffer = stream_thing.getNextInBuffer(&remaining);
    size_t bytesused = stream_thing.encoder_getData(buffer, remaining);  // reads as much as we ask for
    stream_thing.advanceInBuffer(bytesused);
  } // end of readyForData()  
}

void encoder_task(void *params)
{
  const int delay_in_ms = RTOS_DELAY_ENCODER_TASK;  // 250ms per 128kbps buffer, 167ms per 192kbps buffer
  while (true) {
    encode();
    vTaskDelay(portTICK_PERIOD_MS * delay_in_ms);
  }
}

void icy_task(void *params)
{
  const int delay_in_ms = 10000;  // 10 seconds
  while (true) {
    // do the delay at the top of the loop, so that we aren't checking for 
    // a lost connection as soon as the task starts
    vTaskDelay(portTICK_PERIOD_MS * delay_in_ms);
    if (!wifi_thing.isIcecastBroadcastStillConnected()) {
      Serial.println("Remote icecast server has disconnected .. trying to reconnect");
      if (wifi_thing.startIcecastBroadcast()) {
        Serial.println("ICY Broadcast started!");
      } else {
        Serial.println("ICY failed to start!");
      }
    }
  }  
}

#if USE_PIN_CONTROLS
void pins_task(void *params)
{
  const int delay_in_ms = 250;  // 4 times a second
  while (true) {
    vTaskDelay(portTICK_PERIOD_MS * delay_in_ms);
    pins_thing.updateVolume();
    pins_thing.getSwitchState();
  }
}
#endif

#define EXTRAHEAP 0

void start_rtos_tasks()
{
  xTaskCreatePinnedToCore(server_task, "Server Task", 4096+EXTRAHEAP, NULL, 1, NULL, 0); // changed to processor 0 !! from 1

  if (stream_thing.run_not_wait) {
    if (stream_thing.listen_dont_encode) {
      xTaskCreatePinnedToCore(listener_task, "Listener Task", 2048+EXTRAHEAP, NULL, 1+RTOS_HIPRIORITY_VLSI, NULL, 1);
    } else {
      xTaskCreatePinnedToCore(encoder_task, "Encoder Task", 2048+EXTRAHEAP, NULL, 1+RTOS_HIPRIORITY_VLSI, NULL, 1);
      xTaskCreatePinnedToCore(icy_task, "Icy Reconnect Task", 4096+EXTRAHEAP, NULL, 1, NULL, 0); // changed to processor 0 !! from 1
    }
  }

#if USE_PIN_CONTROLS
  xTaskCreatePinnedToCore(pins_task, "Hardware Pins Task", 4096+EXTRAHEAP, NULL, 1, NULL, 0);
#endif

  Serial.println("Toolkit started up with RTOS tasks");
  //Serial.printf("Tick timing is %u ticks per millisecond\n", portTICK_PERIOD_MS);

#if USE_RTOS_TASKS & USE_RTOS_DREQ_DELAY
  Serial.println("RTOS + RTOS DREQ DELAY are ON");
  //Serial.printf("Maximum Priority = %u\n", configMAX_PRIORITIES); // prints out 25
#endif

}

//------------------------------------------------------------------------------------
//
// Handle live changes to the playback and recording volume
//

// live updates need to look for:
//  listen_volume FLOAT .. playback volume for the VS1063a        update_playbackVolume()
//  agc_not_manual UINT .. agc on off .. set these in the encoder update_recordVolume();
//  manual_gain_level FLOAT
//  agc_maximum_gain FLOAT

const char *keys[] = {
  "listen_volume",
  "agc_not_manual",
  "manual_gain_level",
  "agc_maximum_gain",
  NULL
};

enum {
  uLISTEN_VOL = 0,
  uNONE = 4
};

static void update_volumes(const char *name, const char *value)
{
  uint32_t i = 0;
  while (NULL != keys[i]) {
    if (0==strcmp(keys[i],name)) {
      break;
    }
    i++;
  }
  switch (i) {
    case uNONE :
      break;
    case uLISTEN_VOL :
      stream_thing.update_playbackVolume();
      //Serial.println("playback volume updated");
      break;
    default :
      stream_thing.update_recordVolume();
      //Serial.println("record volume updated");
      break;
  }
}

//------------------------------------------------------------------------------------
//
// Setup / Startup
//

void setup() {
  boolean force_waiting_mode = false; // set to true if anything goes wrong
  
  // Setup serial monitor/console
  Serial.begin(115200);
  Serial.println("\n\nWave Farm Toolkit!");

  //--------------------------------------------------
  // Load settings from internal flash drive)
  //

  if (!ToolkitFiles::begin()) {
    Serial.println("ERROR starting FileSystem!");
    force_waiting_mode = true; // don't run the audio stream until we have settings
  } else { // load settings
    Serial.println("--------------------------");
    if (!ToolkitFiles::loadSettings()) {
      Serial.println("No settings to load!");
      force_waiting_mode = true; // don't run the audio stream until we have settings
      SettingItem::loadSettingsFromBuffer(default_settings, DEFAULT_SETTINGS_SIZE);
      Serial.println("Starting with builtin default settings");
    }
    Serial.println("SETTINGS:");
    SettingItem::printSettingsToSerial();
    Serial.println("--------------------------");

  }

  delay(2*1000);

  //--------------------------------------------------
  // VLSI STUFF
  
  stream_thing.encoder_setup();
  if (force_waiting_mode) {
    stream_thing.run_not_wait = false;
  }
  
  //--------------------------------------------------
  // WiFi STUFF - start the WiFi local+AP server

  wifi_thing.setDefaultIndexPage(default_index_page, DEFAULT_INDEX_PAGE_SIZE);
  wifi_thing.begin();

  //--------------------------------------------------
  // Setup the Streamer
  
  if (stream_thing.run_not_wait) {
    if (stream_thing.listen_dont_encode) {
      stream_thing.start_listener();
    } else { // startup as encoder
      Serial.println("Starting in transmitter mode.");
      if (wifi_thing.startIcecastBroadcast()) {
        Serial.println("ICY Broadcast started!");
      } else {
        Serial.println("ICY failed to start!");
      }
      stream_thing.encoder_start();
    }
  } else {
    Serial.println("Starting in Waiting mode.");
  }

  //--------------------------------------------------
  // Link the WiFi STUFF to the Streamer and the live updates function

  wifi_thing.setMP3DataStreamFunction(Streamer::getNextOutBuffer);
  wifi_thing.setWSLiveChangesFunction(update_volumes);


#if USE_PIN_CONTROLS
  pins_thing.begin();
#endif 

  //--------------------------------------------------
  // RTOS
#if USE_RTOS_TASKS
  start_rtos_tasks();
#endif
} // end of setup()

//------------------------------------------------------------------------------------
// Normal Arduino run loop
//
// The FreeRTOS idle task is used to run the loop() function whenever there is no 
// unblocked FreeRTOS task available to run. In the trivial case, where there are 
// no configured FreeRTOS tasks, the loop() function will be run exactly as normal, 
// with the exception that a short scheduler interrupt will occur every 15 ms.
//

void loop() {
#if USE_RTOS_TASKS
  // not sure if this is useful .. but it should send the scheduler back to
  // the other tasks a bit faster .. ??
  const int delay_in_ms = 10000;  // 10 seconds
  vTaskDelay(portTICK_PERIOD_MS * delay_in_ms);
#else

  wifi_thing.run();

  if (!stream_thing.run_not_wait) {
    return;
  }
  
  if (stream_thing.listen_dont_encode) { // LISTENING

    listen();

  } else { // ENCODING

    encode();

  } // end of ENCODING
  
#endif
} // end of loop()

// END OF InternetRadioSketch.ino

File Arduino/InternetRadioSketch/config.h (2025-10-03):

//
// config.h
//
// compilation options for the Toolkit
//

// Set to 1 to use the RTOS scheduler
// Set to 0 to use a single main run loop
#define USE_RTOS_TASKS 1

// Set to 1 to use DREQ delays (yeilds) when
// running in RTOS mode
// This means that the VLSI handshaking will not block
// other tasks
#define USE_RTOS_DREQ_DELAY 1

// Delay times are in milliseconds
#define RTOS_DELAY_SERVER_TASK      5
#define RTOS_DELAY_LISTENER_TASK    10
#define RTOS_DELAY_ENCODER_TASK     30  // smaller=fewer chirps

// Set to 1 to run the VLSI streaming tasks at higher
// priority than the Web/WiFi tasks
// Set to 0 otherwise
// If the priority is higher then the VLSI tasks should
// still run even when the WiFi server is blocking
#define RTOS_HIPRIORITY_VLSI 1

// Turn on/off use of GPIO input pin controls (volume + switch)
#define USE_PIN_CONTROLS 1

//
// END OF config.h

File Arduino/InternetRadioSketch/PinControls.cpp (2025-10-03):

//
// PinControls.cpp

#include "PinControls.h"
#include "src/ToolkitFiles/ToolkitFiles.h"
#include "src/ToolkitWiFi/websocket.h"
#include "src/ToolkitWiFi/http_file.h"

PinControls::PinControls()
{
}

PinControls::~PinControls()
{
    // nada
}

void PinControls::begin()
{
    pinMode(GPIO_SWITCH, INPUT_PULLUP);
//    pinMode(GPIO_VOLUME, INPUT);
//    adcAttachPin(GPIO_VOLUME);
//    adc1_config_width(ADC_WIDTH_12Bit);
//    adc1_config_channel_atten(ADC1_CHANNEL_7, ADC_ATTEN_DB_11);
}

static double readVolumeKnob()
{
    static double old_v = -1.0;
    double v = analogRead(GPIO_VOLUME);
    if (v > 4086) { v = 4086 ;}
    if (v < 6) { v = 6; }
    v = v - 6.0;
    v = v / 40.80;  // 0.0 to 100.0

    // The analog read has a lot of noise on it.
    // To filter this out, change the volume to an integer with a 
    // range of approx. 20
    v = v / 5.0;    // 0.0 to 20.0
    int vi = v;     // this gets rid of noise on the line
    v = vi;
    v = v / 20.0;
    return v;
}

void PinControls::updateVolume()
{
    static double old_v = -1.0;
    double v = readVolumeKnob();
    if (v != old_v) {
        if (-1.0 != old_v) {
            // send it to listen_volume, update VLSI, update WS clients
            // send it as a WS message so that it propogates everywhere
            const char *name = "listen_volume";
            static char value[32];
            sprintf(value, "%1.2f", v);
            SettingItem::updateOrAdd(name, value);
            ToolkitFiles::saveSettings();
            websocket_broadcast(name, (const char *) value);
            ToolkitWiFi_Server::handleWSLiveChanges(name, value);
            Serial.printf("Hardware volume =  %1.2f\n", v);
        }
        old_v = v;
    }  
}

boolean PinControls::getSwitchState()
{
    static int old_s = -1;
    int s = digitalRead(GPIO_SWITCH);
    if (s != old_s) {
        Serial.printf("Hardware switch = %d\n", s);
        old_s = s;
        // the switch will turn on kiosk mode
        http_turnOnKioskMode(s);
    }
}

//
// END OF PinControls.cpp

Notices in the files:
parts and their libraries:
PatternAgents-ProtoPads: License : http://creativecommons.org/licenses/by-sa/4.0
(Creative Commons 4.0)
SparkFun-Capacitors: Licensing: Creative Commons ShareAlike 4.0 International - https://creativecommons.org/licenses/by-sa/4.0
